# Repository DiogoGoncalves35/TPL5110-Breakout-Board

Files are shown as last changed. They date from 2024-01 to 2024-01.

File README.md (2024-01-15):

# Low Power TPL5110 Breakout Board



This small breakout board is designed arround the [TPL5110 Timer](https://www.ti.com/lit/ds/symlink/tpl5110.pdf?ts=1704823351945&ref_url=https%253A%252F%252Fwww.google.com%252F)

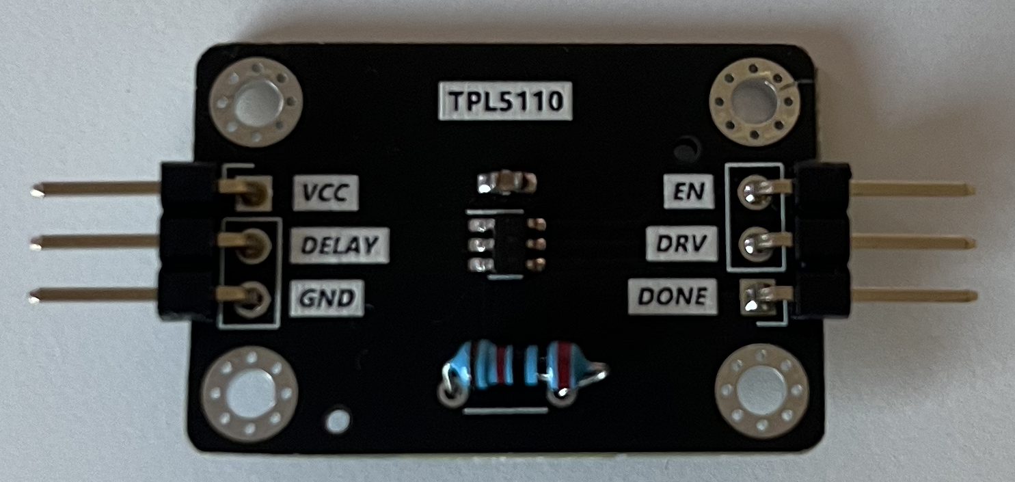
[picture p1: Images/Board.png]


It's a very simple design, by soldering a THT resistor you can choose the time interval between cicles. 

With 5V power it only draws 50 nA while in standby. Measurements were done with [nrF Power Profiler Kit II](https://www.nordicsemi.com/Products/Development-hardware/Power-Profiler-Kit-2).

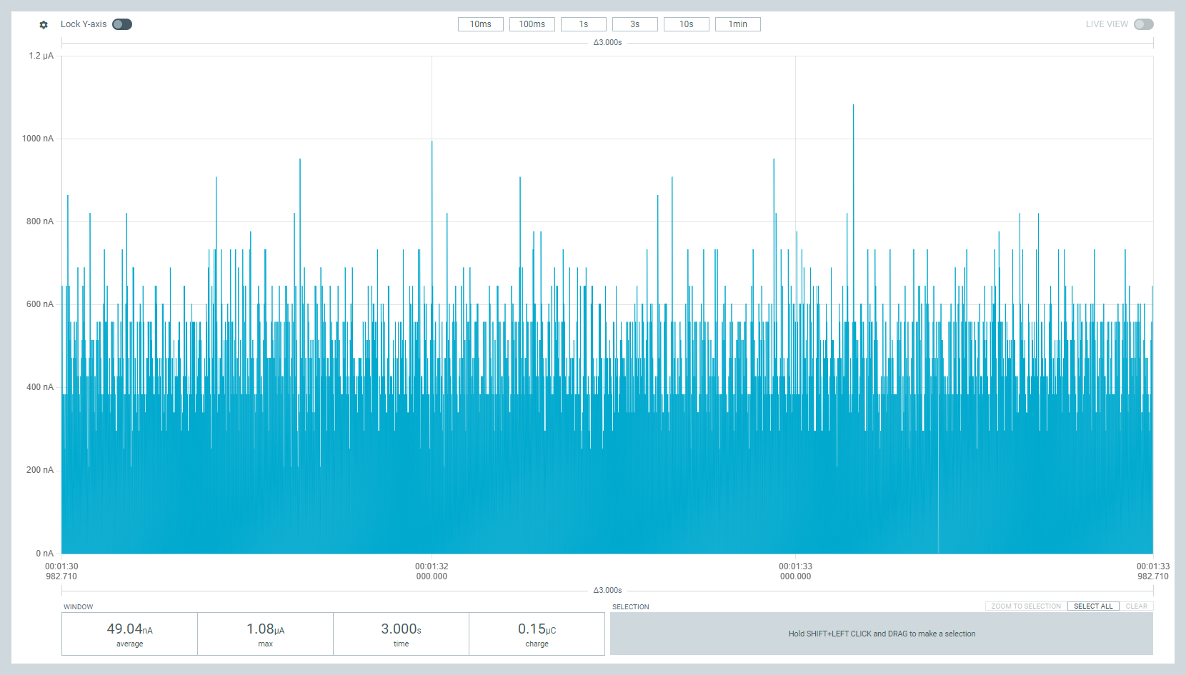
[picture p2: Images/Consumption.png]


Circuit was tested with IRF9Z24N P-Channel Mosfet. It was added a 10k pull down resistor to the DONE pin for better stability, breadboard parasitic capacitance can cause noise on some lines. The mosfet controls the Arduino Uno board and after 10 seconds the Arduino sends a DONE signal to turn off.



------------

### Schematic

The [schematic](/PCB/Schematic.pdf) basicly exposes every pin to the connectors. A decoupling capacitor was added on the power rail. The resistor is responsible for the time period.

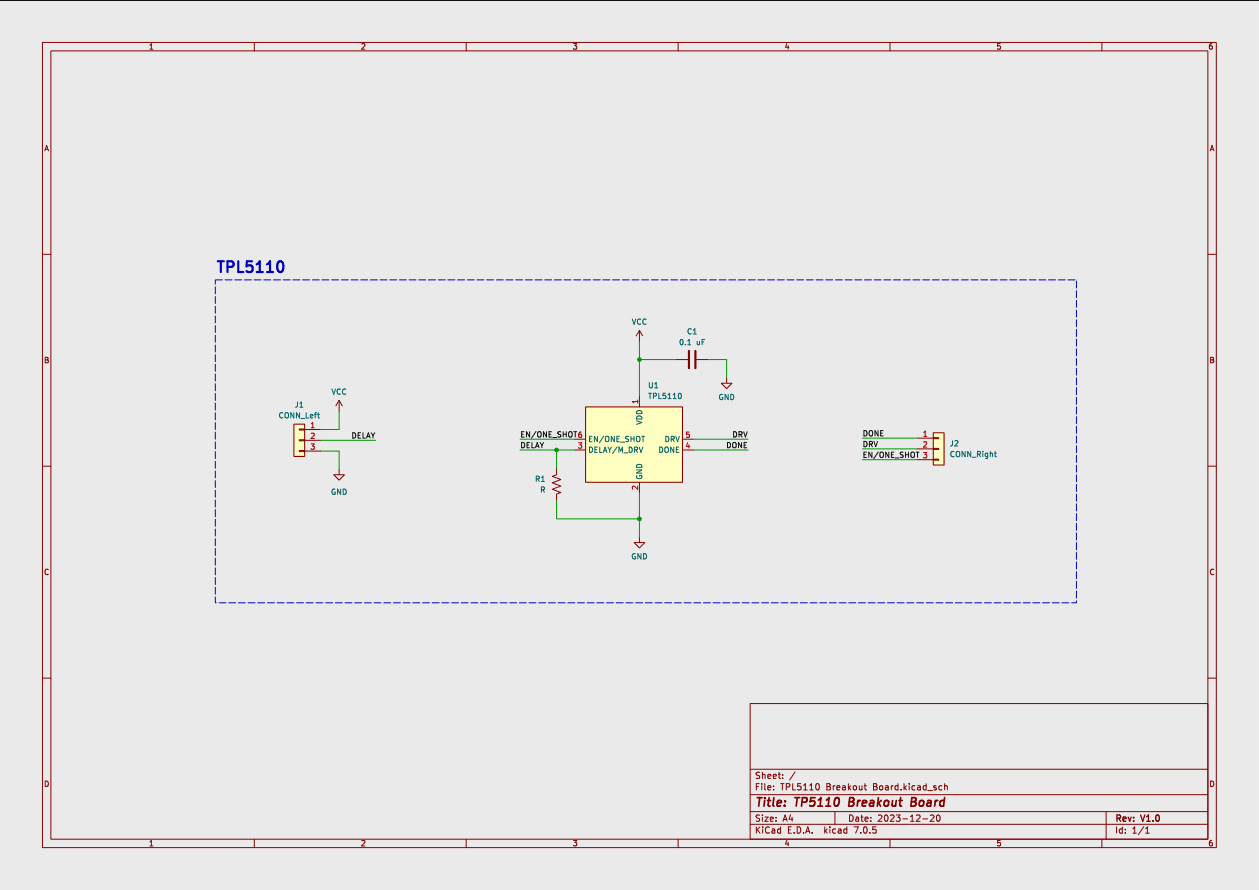
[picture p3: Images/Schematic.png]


------------

### PCB

[This PCB](/PCB) has a very simple design, it's a 1.6 mm board with 2 copper layers, both connect to GND. 

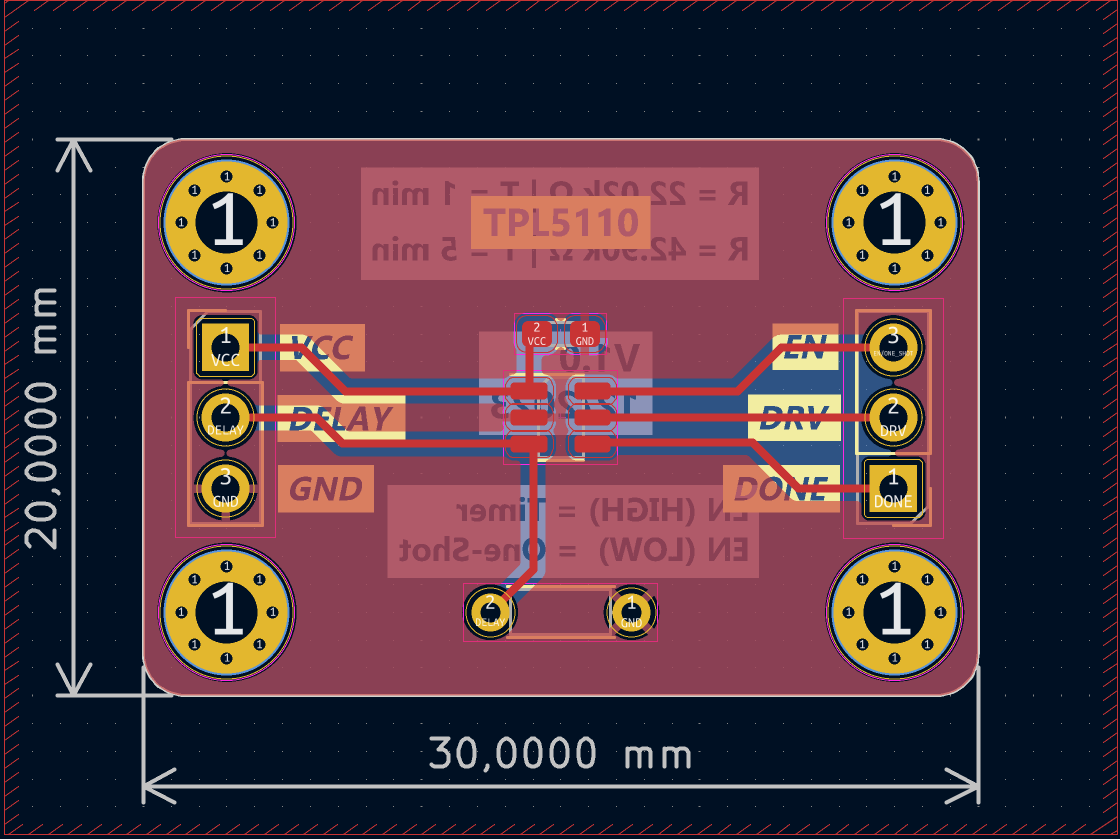
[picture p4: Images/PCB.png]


------------

### Known issues

- Parasitic capacitance but it could be related to breadboard

------------

### To-Do

- No updates for now

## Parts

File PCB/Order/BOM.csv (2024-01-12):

Reference | Value | Footprint | LCSC | Qtd
C1 | 0.1 uF | Capacitor_SMD:C_0603_1608Metric_Pad1.08x0.95mm_HandSolder | C14663 | 1
J1 | CONN_Left | Connector_PinHeader_2.54mm:PinHeader_1x03_P2.54mm_Vertical |  | 1
J2 | CONN_Right | Connector_PinHeader_2.54mm:PinHeader_1x03_P2.54mm_Vertical |  | 1
R1 | R | Resistor_THT:R_Axial_DIN0204_L3.6mm_D1.6mm_P5.08mm_Horizontal |  | 1
U1 | TPL5110 | Package_TO_SOT_SMD:SOT-23-6 | C125830 | 1

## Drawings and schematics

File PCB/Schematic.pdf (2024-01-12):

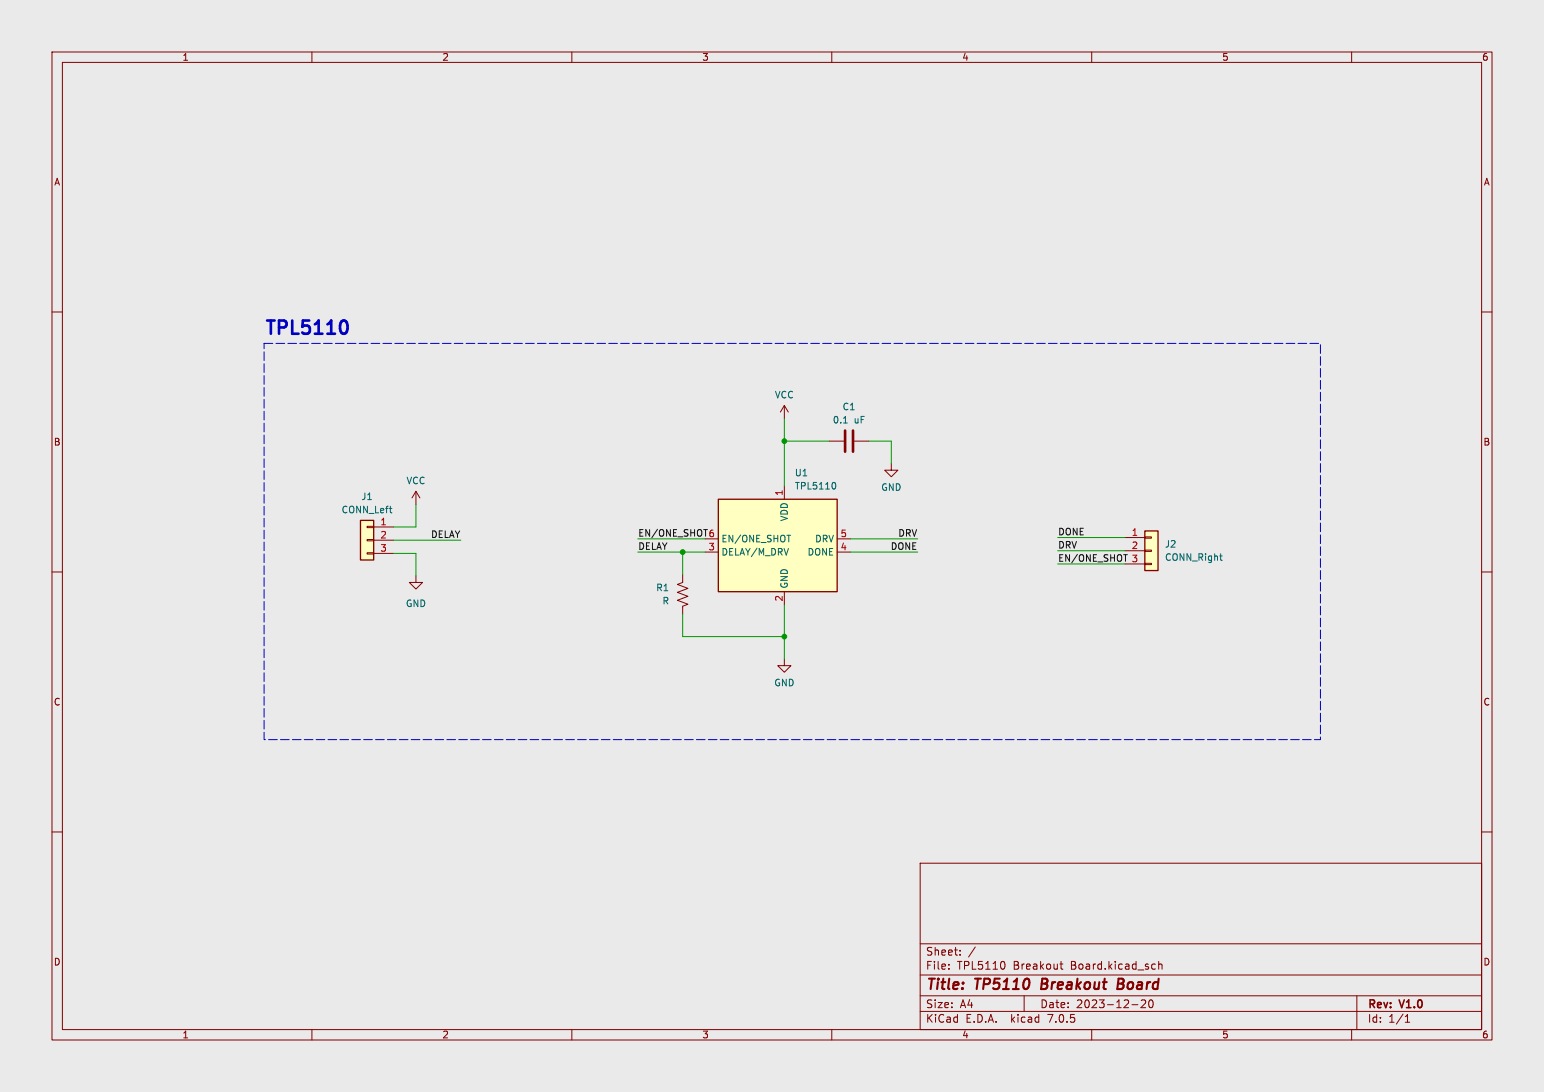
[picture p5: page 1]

2 DELAY/M_DRV 3 DONE 4 DRV 5 EN/ONE_SHOT 6 U1 TPL5110 R1R

Id: 1/1 Title: TP5110 Breakout Board

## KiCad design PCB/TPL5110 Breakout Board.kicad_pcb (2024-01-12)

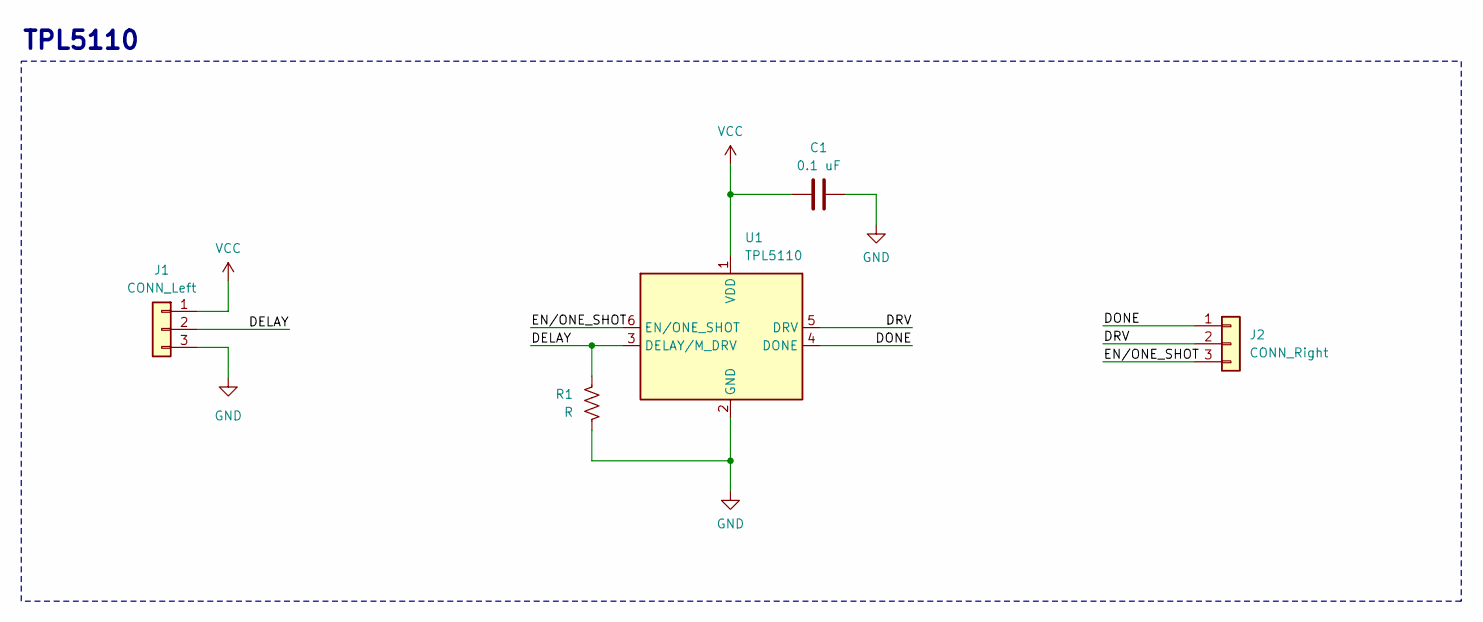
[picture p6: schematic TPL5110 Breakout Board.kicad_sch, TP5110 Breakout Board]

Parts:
C1: 0.1 uF; C_0603_1608Metric_Pad1.08x0.95mm_HandSolder; LCSC C14663
J1: CONN_Left; PinHeader_1x03_P2.54mm_Vertical
J2: CONN_Right; PinHeader_1x03_P2.54mm_Vertical
R1: R; R_Axial_DIN0204_L3.6mm_D1.6mm_P5.08mm_Horizontal
U1: TPL5110; SOT-23-6; LCSC C125830

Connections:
/DELAY: J1.2, R1.2, U1.3 (DELAY/M_DRV)
/DONE: J2.1, U1.4 (DONE)
/DRV: J2.2, U1.5 (DRV)
/EN/ONE_SHOT: J2.3, U1.6 (EN/ONE_SHOT)
GND: C1.1, J1.3, R1.1, U1.2 (GND)
VCC: C1.2, J1.1, U1.1 (VDD)

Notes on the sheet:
TPL5110

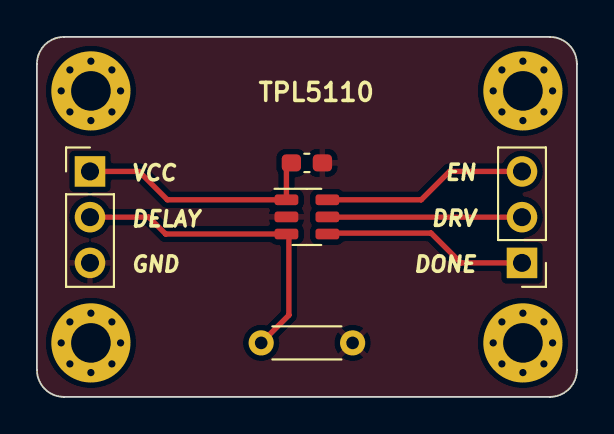
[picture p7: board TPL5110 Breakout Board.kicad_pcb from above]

Board: 2 copper layers, 30.0 x 20.0 mm, 5 parts (0 on the bottom side), 6 nets.
